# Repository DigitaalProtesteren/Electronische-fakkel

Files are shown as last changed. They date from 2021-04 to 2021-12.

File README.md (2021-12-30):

# Electronische-fakkel

Een electronische fakkel voor een fakkeloptocht.

## Benodigde materialen & gereedschap

* Arduino micro of Arduino nano (makkelijk aan te sluiten vanwege de USB connector) optioneel kan een andere Arduino ook of een ESP8266 of ESP32 maar dan moet je meer solderen.
* (Optioneel) Elektrolytische condensator van 470 uF of meer (10V of meer)
* 8 x 32 pixel flexibel ws2812 matrix
  Verkrijgbaar bij o.a. de volgende webshops:
  * https://nl.aliexpress.com/item/33025679652.html
  * https://www.hobbyelectronica.nl/product/8x32-rgb-ws2812b-led-flex-module/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
  * https://nl.grandado.com/products/ws2812b-led-digitale-flexibele-dc5v-individueel-adresseerbare-panel-licht-ws2812-8x8-16x16-8x32-module-matrix-scherm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
  * https://www.amazon.nl/dp/B07KT1H481
  * https://www.tinytronics.nl/shop/nl/diversen/led-matrix/ws2812b-digitale-5050-rgb-led-matrix-32x8-flexibel
* Powerbank met USB aansluiting
* USB kabel die past op de Arduino micro of nano

* Soldeergereedschap (soldeerbout met medium of kleine punt en soldeer)
* ducttape
* dun draad met vaste kern of een stukje (dun) touw

## Instructies

Desoldeer de aansluiting voor data output (de mannelijke connector) van het scherm maar bewaar de connector, die wordt in de volgende stap hergebruikt. In plaats van desolderen kan je deze ook vlak bij het scherm losknippen.
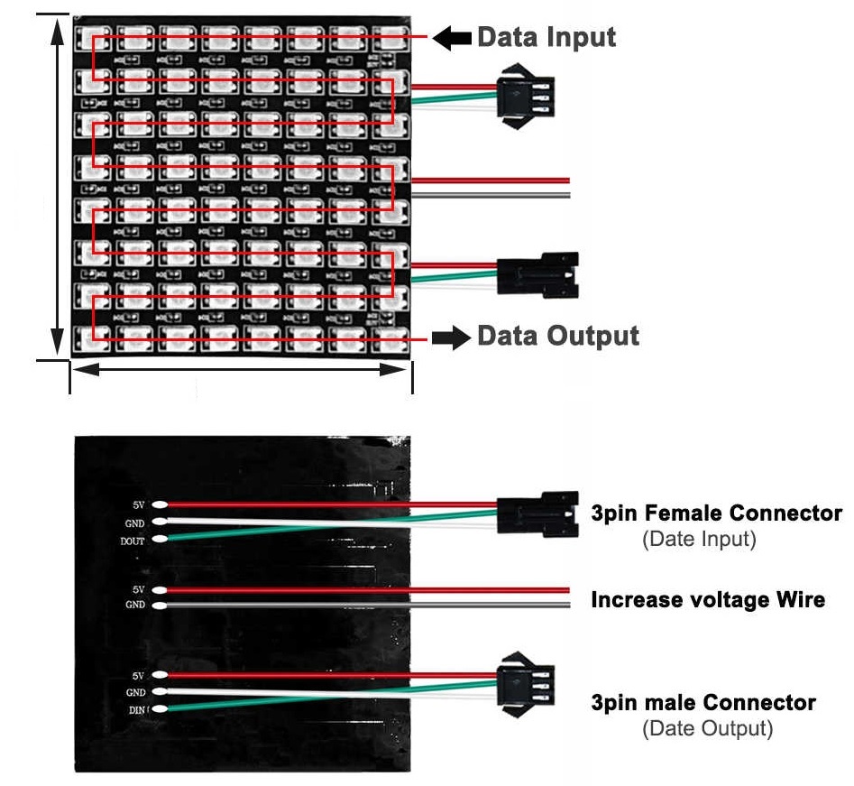
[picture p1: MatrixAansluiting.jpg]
Aansluitingen scherm


Soldeer de net verkregen connector aan de Arduino:
* Rode draad op de 5V aansluiting.
* Zwarte of witte draad op GND.
* Groene draad op pin 6 (bij een ESP8266 of ESP32 sluit je de groene draad aan op pin 13 - D3).

Soldeer eventueel de elektrolytische condensator op de losse rode en witte of rode en zwarte draad die van het scherm afkomt (in de afbeelding "Increase Voltage Wire genoemd). 

LET OP, de condensator heeft een witte streep of aanduiding die de negatieve kant aangeeft. Deze dient op de witte of zwarte draad aangesloten te worden, de andere kant van de condensator is voor de rode draad. Controleer of je de polariteit goed hebt aangesloten en isoleer de aansluitingen met ducttape.

Sluit de Arduino aan op de computer en upload de sketch (fakkel.ino).

Maak van het scherm een rolletje (niet te strak) en plak met ducttape eventueel de arduino en de condensator aan de binnenkant vast. Een deel van het scherm zal hierdoor niet zichtbaar zijn maar dat maakt niet uit voor het effect. Bind tussen de LEDs een touwtje of draadje zodat het scherm een rolletje blijft.

Plak het geheel met ducttape vast op een (bamboe)stokje. Zorg dat de stok niet te zwaar of stevig is om inbeslagname te voorkomen anders kunnen de instanties de stok zien als een slagwapen.

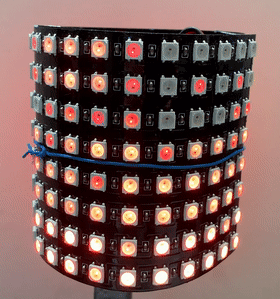
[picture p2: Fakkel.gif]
Fakkel


## Optionele houder

Optioneel kan je een houder printen (bestand Fakkel V2.stl), door in het midden een bout en in de andere helft een moer met hotglue vast te zetten kan je ze op elkaar vastdraaien, in de rand kan je dan de matrix vastklemmen. Tip: plak de matrix in de onderste (die met het doorlopende gat) houder vast met wat stukjes ducttape, de uiteinden overlappen een paar millimeter zodat het een geheel wordt.

In de onderste houder kan je vervolgens iets maken om de fakkel op vast te zetten.

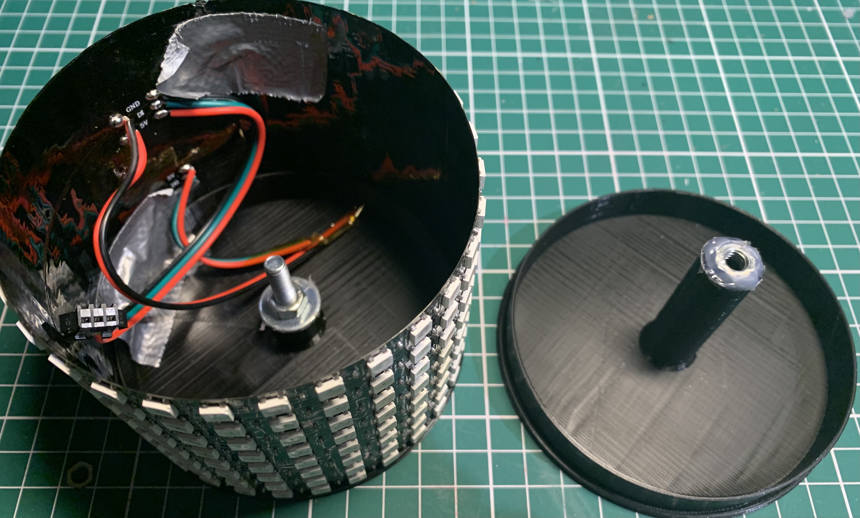
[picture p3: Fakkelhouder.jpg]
Fakkelhouder


**Let op: Als je dit doet zorg er dan voor dat je electronica voldoende afgeschermd is zodat je geen kortsluiting kan krijgen als een deel per ongeluk tegen de bout aan komt. Je kan dit doen door bijvoorbeeld  een stukje ducttape op de onderdelen te plakken.**

## Optionele batterij
In plaats van een powerbank kan je ook een IKEA batterij en een DC/DC omvormer gebruiken, bijvoorbeeld de Braunit:
 * https://www.ikea.com/nl/nl/p/braunit-batterijpakket-10433258/

In combinatie met een goedkope DC/DC omvormer, bijvoorbeeld verkrijgbaar bij de volgende webshops:
 * https://nl.aliexpress.com/item/32880983608.html
 * https://www.hobbyelectronica.nl/product/lm2596s-dc-dc-regelbare-step-down/
 * https://www.amazon.nl/Allayu-converter-Step-Down-Verstelbare-Converter/dp/B09GY1GZHK/ref=sr_1_3_sspa
 * https://www.tinytronics.nl/shop/nl/power/spanningsconverters/buck-(step-down)-converters/mini-dc-dc-verstelbare-step-down-buck-converter-0.5a-mp2307

Voor de batterij kan je een houder printen, op Thingsverse is een mooie houder te vinden (https://cdn.thingiverse.com/assets/b0/ff/df/dc/c7/Battery_constraint.stl). Je kan de print eventueel na 1-2 cm afbreken, veel meer heb je niet echt nodig.
In plaats van de officiële connector (https://nl.aliexpress.com/item/4000332107587.html) kan je ook gewoon twee stukjes metaal pakken die tussen de contacten van de batterij passen:
 * Knip twee stukje metaal uit van ongeveer 10 x 5 mm.
 * Vouw de stukjes over de lengte in een hoek van 90 graden.
 * Knip uit de houder het plastic weg wat voor de batterijcontacten zit, laat de zijkanten zitten.
 * Soldeer aan beide stukjes metaal een draadje. (Niet vergeten anders smelt de hotglue door je soldeerbout.)
 * Plaats de batterij in de houder en plaats de stukjes metaal zodanig dat ze contact maken met de uiterste twee contacten van de batterij.
 * Lijm de stukjes metaal vast met hotglue (let op dat je geen lijm op de batterij krijgt).

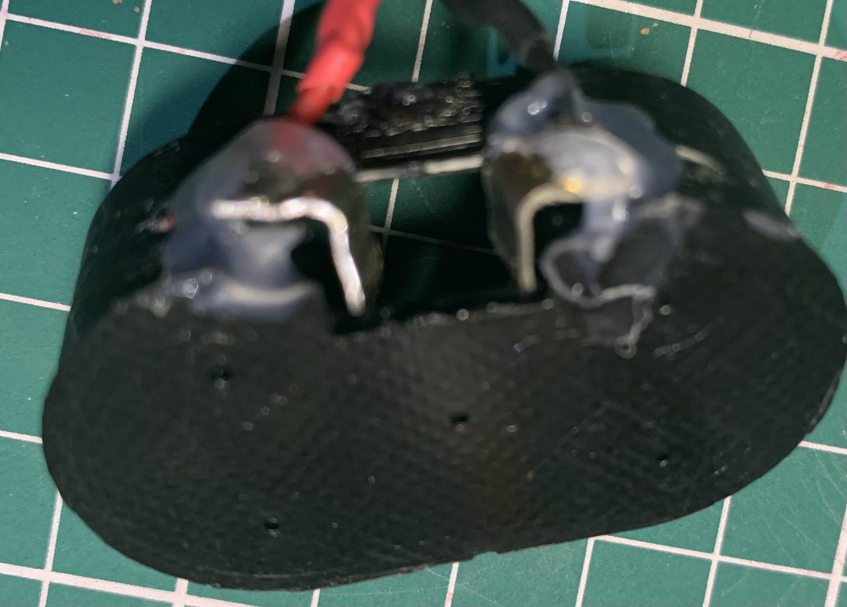
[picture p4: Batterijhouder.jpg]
Batterijhouder


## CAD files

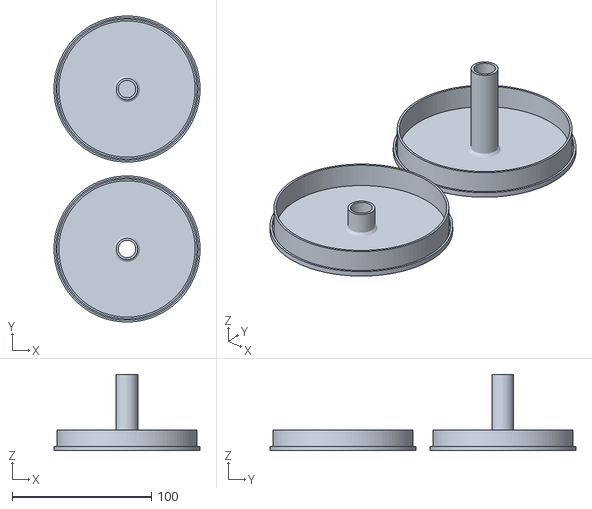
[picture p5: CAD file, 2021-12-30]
Fakkel v2.stl
105.0 x 220.0 x 55.0

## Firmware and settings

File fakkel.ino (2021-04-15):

/**
 * MatrixFireFast - A fire simulation for NeoPixel (and other?) matrix
 * displays on Arduino (or ESP8266) using FastLED.
 *
 * Author: Patrick Rigney (https://www.toggledbits.com/)
 * Copyright 2020 Patrick H. Rigney, All Rights Reserved.
 *
 * Github: https://github.com/toggledbits/MatrixFireFast
 * License information can be found at the above Github link.
 *
 * Please donate in support of my projects: https://www.toggledbits.com/donate
 *
 * For configuration information and processor selection, please see
 * the README file at the above Github link.
 */

#include <FastLED.h>

#define VERSION 20275

//#define DISPLAY_TEST  /* define to show test patterns at startup */

/* MATRIX CONFIGURATION -- PLEASE SEE THE README (GITHUB LINK ABOVE) */

#define MAT_TYPE NEOPIXEL   /* Matrix LED type; see FastLED docs for others */
#define MAT_W   32          /* Size (columns) of entire matrix */
#define MAT_H   8          /* and rows */
#if defined(ESP32) || defined(ESP8266)
#define MAT_PIN 13           /* Data for matrix on D3 on ESP8266 */
#else
#define MAT_PIN 6           /* Data for matrix on pin 6 for Arduino/other */
#endif
#undef  MAT_COL_MAJOR       /* define if matrix is column-major (that is pixel 1 is in the same column as pixel 0) */
#define MAT_TOP             /* define if matrix 0,0 is in top row of display; undef if bottom */
#define MAT_LEFT            /* define if matrix 0,0 is on left edge of display; undef if right */
#define MAT_ZIGZAG          /* define if matrix zig-zags ---> <--- ---> <---; undef if scanning ---> ---> ---> */

#define BRIGHT 64           /* brightness; min 0 - 255 max -- high brightness requires a hefty power supply! Start low! */
#define FPS 15              /* Refresh rate */

/* MULTI-PANEL CONFIGURATION -- Do not change unless you connect multiple panels -- See README.md */
/* WARNING -- THIS IS CURRENTLY UNTESTED -- DO NOT ENABLE UNLESS YOU FEEL LIKE BEING MY CRASH TEST MANNEQUIN */
#undef  MULTIPANEL          /* define to enable multi-panel support */
#define PANELS_W    1       /* Number of panels wide */
#define PANELS_H    1       /* Number of panels tall */
#undef  PANEL_TOP           /* define if first panel is upper-left */
#undef  PANEL_ZIGZAG        /* define if panels zig-zag */
/* --- DO NOT CHANGE THESE LINES --- */
#ifndef MULTIPANEL
#define PANELS_H 1
#define PANELS_W 1
#undef PANEL_TOP
#undef PANEL_ZIGZAG
#endif

/* DEBUG CONFIGURATION */

#undef  SERIAL              /* Serial slows things down; don't leave it on. */

/* SECONDARY CONFIGURATION */


/* Display size; can be smaller than matrix size, and if so, you can move the origin.
 * This allows you to have a small fire display on a large matrix sharing the display
 * with other stuff. See README at Github. */
const uint16_t rows = MAT_H * PANELS_H;
const uint16_t cols = MAT_W * PANELS_W;
const uint16_t xorg = 0;
const uint16_t yorg = 0;

/* Flare constants */
const uint8_t flarerows = 2;    /* number of rows (from bottom) allowed to flare */
const uint8_t maxflare = 8;     /* max number of simultaneous flares */
const uint8_t flarechance = 50; /* chance (%) of a new flare (if there's room) */
const uint8_t flaredecay = 14;  /* decay rate of flare radiation; 14 is good */

/* This is the map of colors from coolest (black) to hottest. Want blue flames? Go for it! */
const uint32_t colors[] = {
  0x000000,
  0x100000,
  0x300000,
  0x600000,
  0x800000,
  0xA00000,
  0xC02000,
  0xC04000,
  0xC06000,
  0xC08000,
  0x807080
};
const uint8_t NCOLORS = (sizeof(colors)/sizeof(colors[0]));

uint8_t pix[rows][cols];
CRGB matrix[MAT_H * PANELS_H * MAT_W * PANELS_W];
uint8_t nflare = 0;
uint32_t flare[maxflare];

/** pos - convert col/row to pixel position index. This takes into account
 *  the serpentine display, and mirroring the display so that 0,0 is the
 *  bottom left corner and (MAT_W-1,MAT_H-1) is upper right. You may need
 *  to jockey this around if your display is different.
 */
#ifndef MAT_LEFT
#define __MAT_RIGHT
#endif
#ifndef MAT_TOP
#define __MAT_BOTTOM
#endif
#if defined(MAT_COL_MAJOR)
const uint8_t phy_h = MAT_W;
const uint8_t phy_w = MAT_H;
#else
const uint8_t phy_h = MAT_H;
const uint8_t phy_w = MAT_W;
#endif
#if defined(MULTIPANEL)
uint16_t _pos( uint16_t col, uint16_t row ) {
#else
uint16_t pos( uint16_t col, uint16_t row ) {
#endif
#if defined(MAT_COL_MAJOR)
    uint16_t phy_x = xorg + (uint16_t) row;
    uint16_t phy_y = yorg + (uint16_t) col;
#else
    uint16_t phy_x = xorg + (uint16_t) col;
    uint16_t phy_y = yorg + (uint16_t) row;
#endif
#if defined(MAT_LEFT) && defined(MAT_ZIGZAG)
  if ( ( phy_y & 1 ) == 1 ) {
    phy_x = phy_w - phy_x - 1;
  }
#elif defined(__MAT_RIGHT) && defined(MAT_ZIGZAG)
  if ( ( phy_y & 1 ) == 0 ) {
    phy_x = phy_w - phy_x - 1;
  }
#elif defined(__MAT_RIGHT)
  phy_x = phy_w - phy_x - 1;
#endif
#if defined(MAT_TOP) and defined(MAT_COL_MAJOR)
  phy_x = phy_w - phy_x - 1;
#elif defined(MAT_TOP)
  phy_y = phy_h - phy_y - 1;
#endif
  return phy_x + phy_y * phy_w;
}

#if defined(MULTIPANEL)
uint16_t pos(uint16_t col, uint16_t row) {
#if defined(PANEL_TOP)
    uint16_t panel_y = PANELS_H - ( row / MAT_H ) - 1;
#else
    uint16_t panel_y = row / MAT_H;
#endif
    uint16_t panel_x = col / MAT_W;
#if defined(PANEL_ZIGZAG)
    if ( ( panel_y & 1 ) == 1 ) {
        panel_x = PANELS_W - panel_x - 1;
    }
#endif
    uint16_t pindex = panel_x + panel_y * PANELS_W;
    return MAT_W * MAT_H * pindex + _pos(col % MAT_W, row % MAT_H);
}
#endif

uint32_t isqrt(uint32_t n) {
  if ( n < 2 ) return n;
  uint32_t smallCandidate = isqrt(n >> 2) << 1;
  uint32_t largeCandidate = smallCandidate + 1;
  return (largeCandidate*largeCandidate > n) ? smallCandidate : largeCandidate;
}

// Set pixels to intensity around flare
void glow( int x, int y, int z ) {
  int b = z * 10 / flaredecay + 1;
  for ( int i=(y-b); i<(y+b); ++i ) {
    for ( int j=(x-b); j<(x+b); ++j ) {
      if ( i >=0 && j >= 0 && i < rows && j < cols ) {
        int d = ( flaredecay * isqrt((x-j)*(x-j) + (y-i)*(y-i)) + 5 ) / 10;
        uint8_t n = 0;
        if ( z > d ) n = z - d;
        if ( n > pix[i][j] ) { // can only get brighter
          pix[i][j] = n;
        }
      }
    }
  }
}

void newflare() {
  if ( nflare < maxflare && random(1,101) <= flarechance ) {
    int x = random(0, cols);
    int y = random(0, flarerows);
    int z = NCOLORS - 1;
    flare[nflare++] = (z<<16) | (y<<8) | (x&0xff);
    glow( x, y, z );
  }
}

/** make_fire() animates the fire display. It should be called from the
 *  loop periodically (at least as often as is required to maintain the
 *  configured refresh rate). Better to call it too often than not enough.
 *  It will not refresh faster than the configured rate. But if you don't
 *  call it frequently enough, the refresh rate may be lower than
 *  configured.
 */
unsigned long t = 0; /* keep time */
void make_fire() {
  uint16_t i, j;
  if ( t > millis() ) return;
  t = millis() + (1000 / FPS);

  // First, move all existing heat points up the display and fade
  for ( i=rows-1; i>0; --i ) {
    for ( j=0; j<cols; ++j ) {
      uint8_t n = 0;
      if ( pix[i-1][j] > 0 )
        n = pix[i-1][j] - 1;
      pix[i][j] = n;
    }
  }

  // Heat the bottom row
  for ( j=0; j<cols; ++j ) {
    i = pix[0][j];
    if ( i > 0 ) {
      pix[0][j] = random(NCOLORS-6, NCOLORS-2);
    }
  }

  // flare
  for ( i=0; i<nflare; ++i ) {
    int x = flare[i] & 0xff;
    int y = (flare[i] >> 8) & 0xff;
    int z = (flare[i] >> 16) & 0xff;
    glow( x, y, z );
    if ( z > 1 ) {
      flare[i] = (flare[i] & 0xffff) | ((z-1)<<16);
    } else {
      // This flare is out
      for ( int j=i+1; j<nflare; ++j ) {
        flare[j-1] = flare[j];
      }
      --nflare;
    }
  }
  newflare();

  // Set and draw
  for ( i=0; i<rows; ++i ) {
    for ( j=0; j<cols; ++j ) {
      matrix[pos(j,i)] = colors[pix[i][j]];
    }
  }
  FastLED.show();
}

void setup() {
  FastLED.addLeds<MAT_TYPE, MAT_PIN>(matrix, MAT_W * MAT_H);
  FastLED.setBrightness(BRIGHT);
  FastLED.clear();
  FastLED.show();

  for ( uint16_t i=0; i<rows; ++i ) {
    for ( uint16_t j=0; j<cols; ++j ) {
      if ( i == 0 ) pix[i][j] = NCOLORS - 1;
      else pix[i][j] = 0;
    }
  }

#ifdef SERIAL
    Serial.begin(115200); while (!Serial);
    Serial.print("MatrixFireFast v"); Serial.println(VERSION);
    Serial.print("Pin "); Serial.print(MAT_PIN);
    Serial.print(", brightness "); Serial.print(BRIGHT);
    Serial.print(", FPS "); Serial.println(FPS);
#endif

#ifdef DISPLAY_TEST
  FastLED.clear();
  for ( uint16_t i=0; i<cols; ++i ) {
    matrix[pos(i,0)] = colors[NCOLORS-1];
    FastLED.show();
    delay(1000/FPS);
    matrix[pos(i,0)] = 0;
  }
  for ( uint16_t i=0; i<rows; ++i ) {
    matrix[pos(0,i)] = colors[NCOLORS-1];
    FastLED.show();
    delay(1000/FPS);
    matrix[pos(0,i)] = 0;
  }
  /** Show the color map briefly at the extents of the display. This "demo"
   *  is meant to help establish correct origin, extents, colors, and
   *  brightness. You can cut or comment this out if you don't need it;
   *  it's not important to functionality otherwise.
   */
  uint16_t y = 0;
  FastLED.clear();
  for ( int i=NCOLORS-1; i>=0; --i ) {
    if ( y < rows ) {
      matrix[pos(0,y)] = colors[i];
      matrix[pos(cols-1,y++)] = colors[i];
    }
    else break;
  }
  FastLED.show();
  delay(2000);
#endif
  FastLED.clear();
  FastLED.show();
}

void loop() {
  make_fire();
  delay(10);
}
